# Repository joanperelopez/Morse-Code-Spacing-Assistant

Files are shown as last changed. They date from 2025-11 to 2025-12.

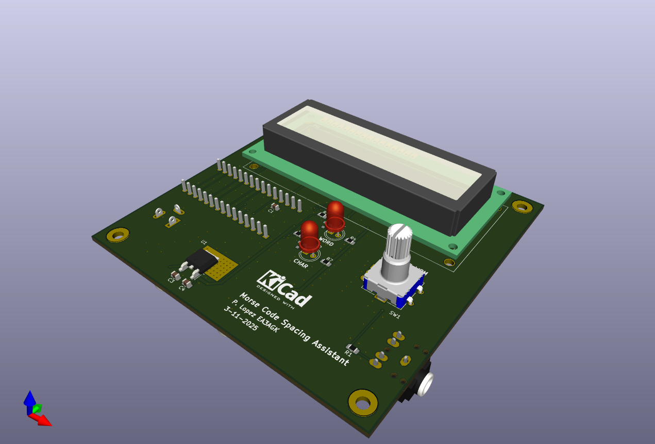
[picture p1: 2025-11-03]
IMAGES/Metronomo_TOP.png

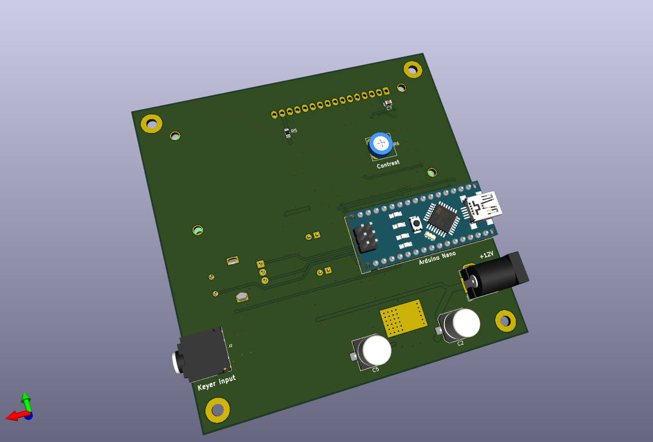
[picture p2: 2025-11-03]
IMAGES/Metronomo_BOT.png

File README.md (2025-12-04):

# Morse-Code-Spacing-Assistant

## 1. Overview
The **CW Visual Metronome** is a training device designed for radio amateurs practicing Morse code (CW).  
It helps the operator maintain correct **Farnsworth timing** between characters and words by providing **visual cues** through two LEDs.

The device monitors the keyer signal, detects symbol endings, and activates visual indicators at precise intervals derived from the selected **effective WPM** (Words Per Minute).

The system is based on an **Arduino Nano**, with a **1602 LCD display** showing the current speed, a **rotary encoder** for adjustment, and a **memory pushbutton** that stores the selected speed in non-volatile EEPROM memory. 

---

## 2. Functional Description

| Function | Description |
|---|---|
| **Keyer input** | Detects the Morse key line. When released, timing intervals begin. |
| **Character LED** | Lights up when the inter-character interval (3 dot units) has elapsed since the last key release. |
| **Word LED** | Lights up when the inter-word interval (7 dot units) has elapsed since the last key release. |
| **Rotary encoder** | Adjusts the effective Farnsworth speed (WPM). |
| **LCD display** | Shows the current Farnsworth speed in WPM. |
| **Memory button** | When pressed (active LOW), stores the current speed in EEPROM. |
| **EEPROM memory** | Retains the last stored speed; restored automatically at startup. |

---

## 3. Timing Definition (Farnsworth Method)

The Farnsworth method keeps the character speed constant but lengthens the spacing between characters and words to achieve a slower **effective WPM** for training.

The base time unit (*dot duration*) is calculated as:

Tdot = 1200 / WPM

| Interval | Duration (dot units) | Description |
|---|---|---|
| Dot (·) | 1 × Tdot | Base unit |
| Dash (–) | 3 × Tdot | Morse standard |
| Intra-character gap | 1 × Tdot | Between elements of a character |
| Inter-character gap | 3 × Tdot | Between two characters |
| Inter-word gap | 7 × Tdot | Between words |

LED indicators:
- **Character LED:** lights after *3 × Tdot* (character spacing).  
- **Word LED:** lights after *7 × Tdot* (word spacing).

---

## 4. User Interface and Operation

1. **Startup**
   - Reads stored speed from EEPROM.
   - Defaults to **15 WPM** if no valid data found.
   - Displays current speed on the LCD.

2. **Adjusting the Speed**
   - Turn the rotary encoder to change the Farnsworth speed.
   - Display updates in real time.

3. **Saving the Speed**
   - Press the *Memory Button* (active LOW) to save current WPM to EEPROM.
   - “Saved in EEPROM” appears briefly on the LCD.

4. **Operating Mode**
   - When the Morse key (active LOW) is pressed, both LEDs turn OFF.
   - After key release:
     - The **Character LED** turns ON after 3 dot units.
     - The **Word LED** turns ON after 7 dot units.
   - When the key is pressed again, both LEDs turn OFF immediately.

---

## 5. Hardware Specifications

| Component | Description |
|---|---|
| **Microcontroller** | Arduino Nano (ATmega328P) |
| **Display** | 1602 alphanumeric LCD |
| **Rotary Encoder** | Incremental (2-channel, mechanical) |
| **EEPROM** | Internal, used for WPM storage |
| **Indicators** | 2 LEDs (character and word) |
| **Memory Button** | Momentary pushbutton, active LOW |
| **Keyer Input** | From key or transceiver, active LOW |
| **Power Supply** | 5 V DC (USB or external) |

---

## 6. Pin Assignments

| Signal | Arduino Pin | Description |
|---|---|---|
| **Keyer input** | D2 | Active LOW, internal pull-up |
| **Encoder A** | D3 | Rotary encoder channel A |
| **Encoder B** | D4 | Rotary encoder channel B |
| **LCD D4** | D5 | Data line 4 |
| **LCD D5** | D6 | Data line 5 |
| **LCD RS** | D7 | Register Select |
| **LCD E** | D8 | Enable |
| **LED (character)** | D9 | Character spacing indicator |
| **LED (word)** | D10 | Word spacing indicator |
| **LCD D6** | D11 | Data line 6 |
| **LCD D7** | D12 | Data line 7 |
| **Memory button** | D21 | Active LOW, internal pull-up |

---

## 7. Electrical Characteristics

| Parameter | Typical Value | Notes |
|---|---|---|
| Supply Voltage | 5 V DC | Standard Arduino Nano |
| Logic HIGH | ≥ 3.0 V | TTL compatible |
| Logic LOW | ≤ 1.0 V | TTL compatible |
| LED Current | 10–15 mA | With 330 Ω series resistors |
| EEPROM Endurance | 100,000 write cycles | Managed via `EEPROM.update()` |

---

## 8. Software Summary

- Language: **C++ (Arduino IDE)**
- Main libraries used:
  - `LiquidCrystal.h` – LCD display control  
  - `RotaryEncoder.h` – rotary encoder handling  
  - `EEPROM.h` – non-volatile memory management
- Main functions:
  - Real-time LED timing based on keyer signal
  - Adjustable Farnsworth WPM
  - EEPROM storage of configuration
  - LCD visual feedback

---

## 9. Default Parameters

| Parameter | Default Value | Range |
|---|---|---|
| **Farnsworth speed** | 15 WPM | 5–40 WPM |
| **Character spacing** | 3 × Tdot | — |
| **Word spacing** | 7 × Tdot | — |

---

Metronomo_TOP
TOP view of the circuit

Metronomo_BOT
BOTTOM view of the circuit

Captura de pantalla 2025-11-12 a las 15 01 24
3D Model of the plastic cover

WhatsApp Image 2025-11-18 at 19 28 20 (1)

WhatsApp Image 2025-11-18 at 19 28 19 (1)

WhatsApp Image 2025-11-18 at 19 28 19

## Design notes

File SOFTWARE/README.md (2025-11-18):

## Last software modifications

### Version V2.2

Aplied an small speaker in pin 13 throug a 4,7 uF capacitor that sound in character and word timeout.

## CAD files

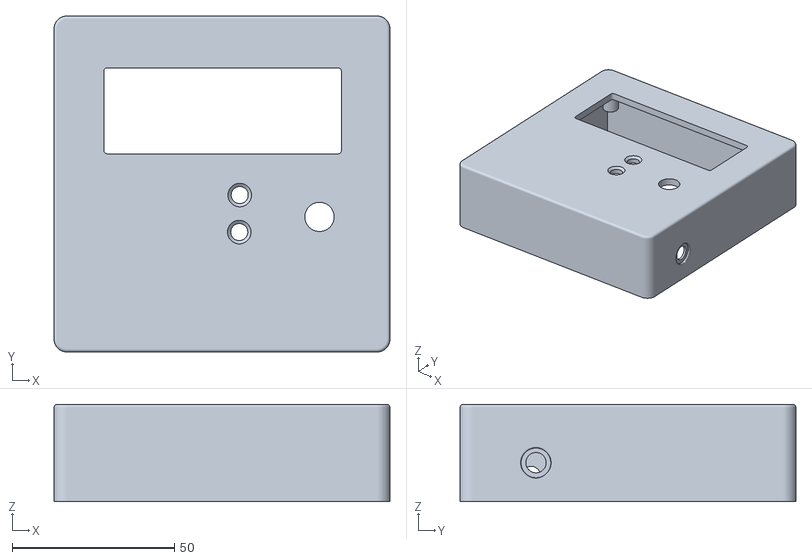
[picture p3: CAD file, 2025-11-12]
STL/caja_superior.stl
103.5 x 103.5 x 30.0

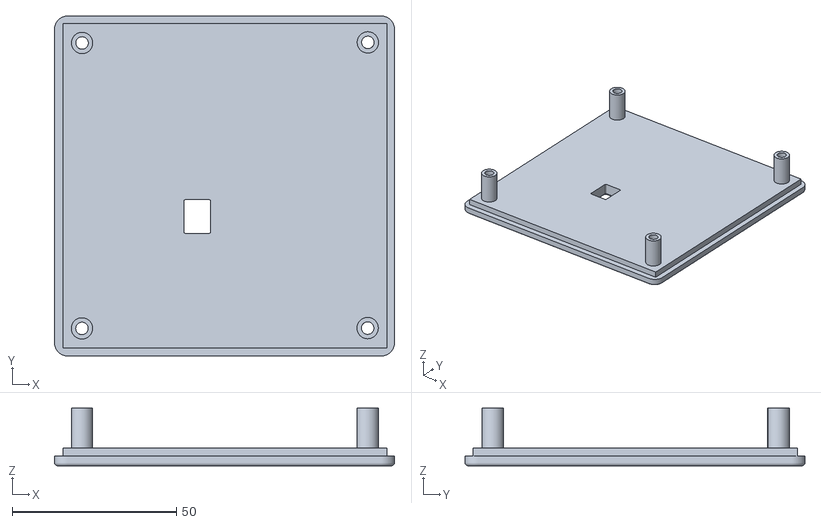
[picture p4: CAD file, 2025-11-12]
STL/Tapa.stl
103.5 x 103.5 x 17.6

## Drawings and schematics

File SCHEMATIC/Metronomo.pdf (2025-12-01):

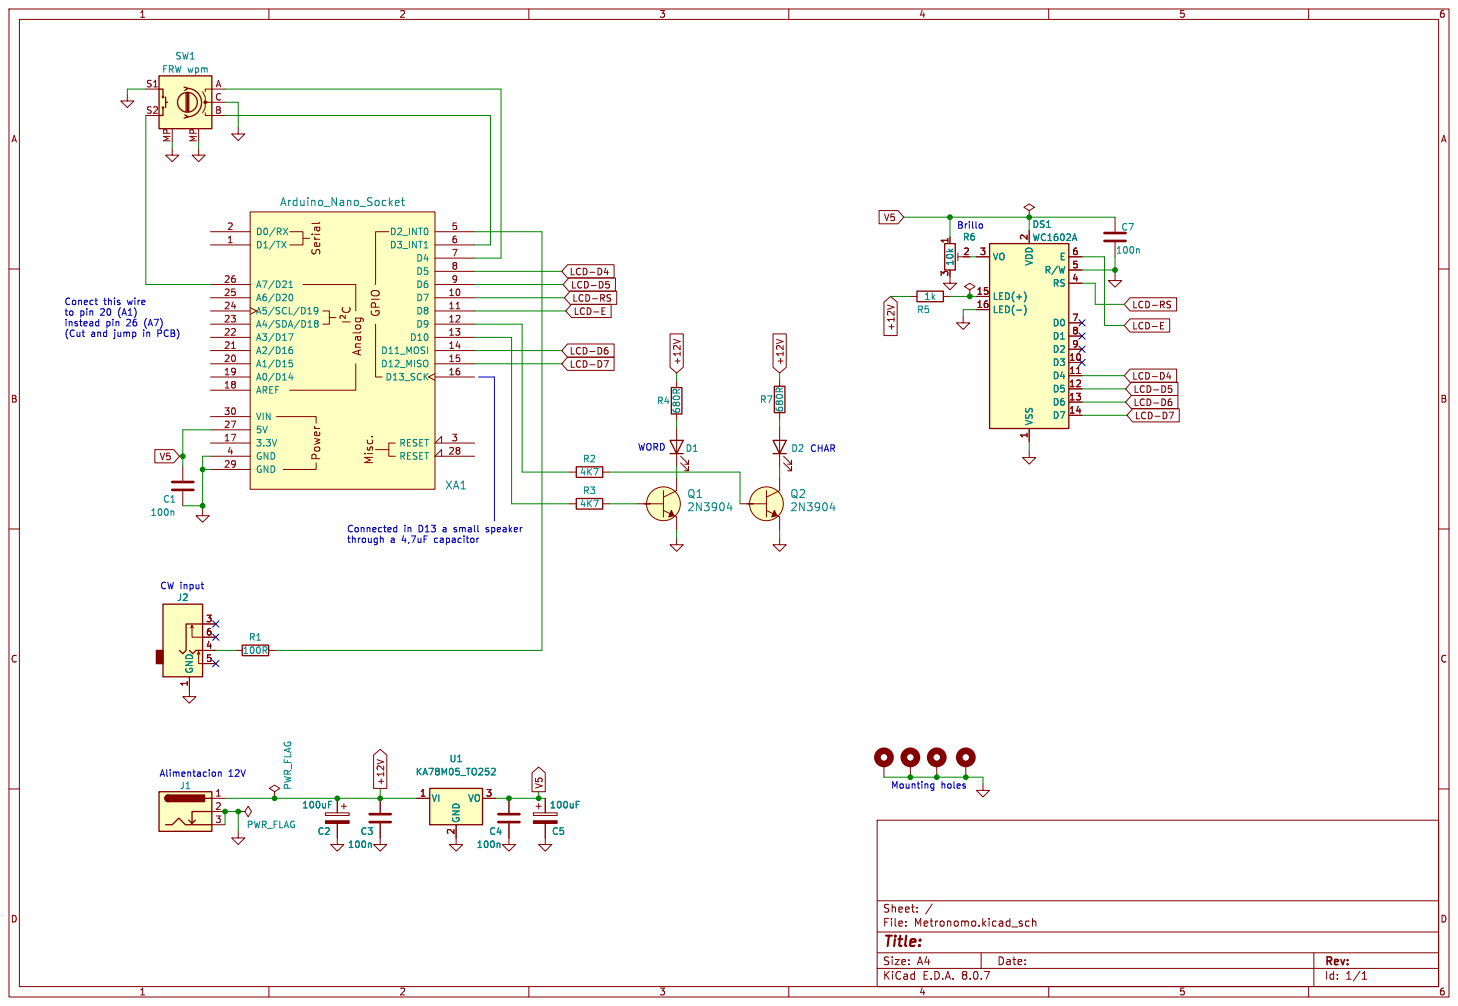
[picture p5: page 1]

LCD-D4 Connected in D13 a small speaker

to pin 20 (A1)
instead pin 26 (A7)
(Cut and jump in PCB)

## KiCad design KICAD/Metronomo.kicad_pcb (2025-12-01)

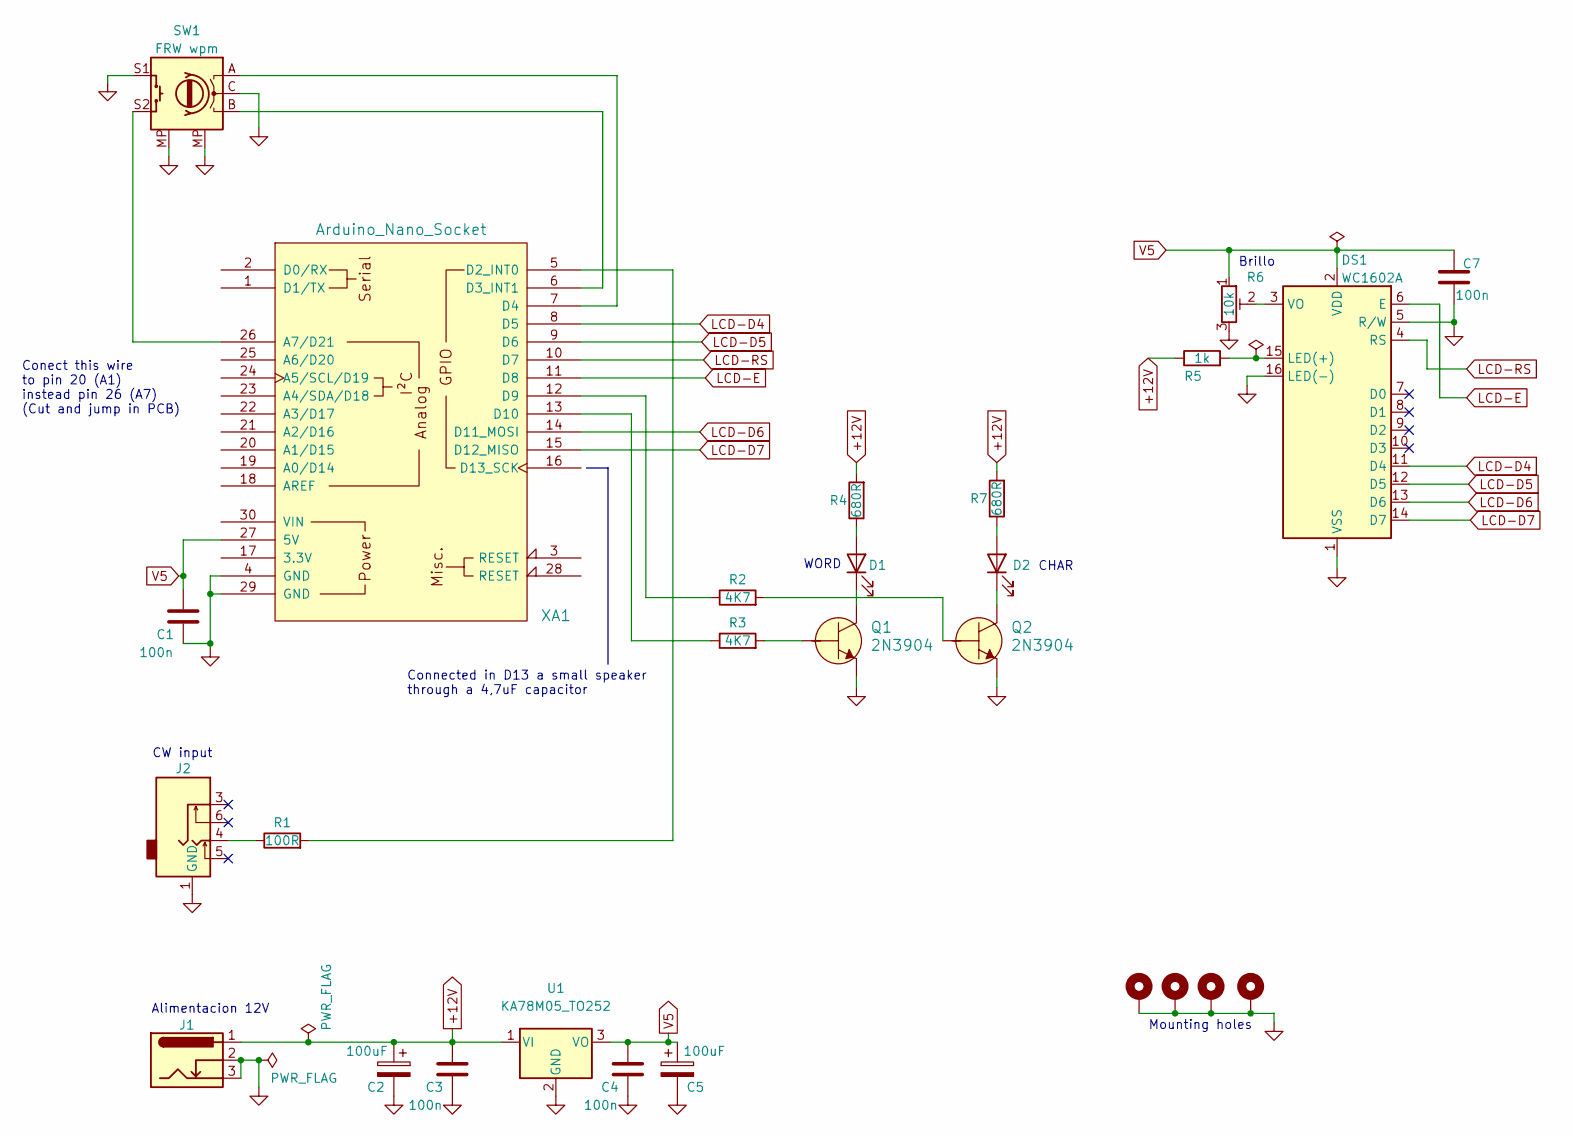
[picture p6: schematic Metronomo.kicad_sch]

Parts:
C1, C3, C4, C7: 100n; C_0805_2012Metric
C2, C5: 100uF; C_Elec_8x10.2
D1, D2: LED; LED_D5.0mm
DS1: WC1602A
H1, H2, H3, H4: MountingHole_Pad; MountingHole_3.2mm_M3_Pad_TopBottom
J1: Barrel_Jack_Switch_Pin3Ring; BarrelJack_GCT_DCJ200-10-A_Horizontal
J2: AudioJack4_PERE; AUDIO-JACK4
Q1, Q2: 2N3904; SOT23-3; MPN 2N3904; Digi-Key_PN 2N3904CS-ND
R1: 100R; R_0805_2012Metric_Pad1.20x1.40mm_HandSolder
R2, R3: 4K7; R_0805_2012Metric_Pad1.20x1.40mm_HandSolder
R4, R7: 680R; R_0805_2012Metric_Pad1.20x1.40mm_HandSolder
R5: 1k; R_0805_2012Metric_Pad1.20x1.40mm_HandSolder
R6: 10k; Potentiometer_Piher_PT-10-V10_Vertical
SW1: FRW wpm; RotaryEncoder_Alps_EC11E_Vertical_H20mm
U1: KA78M05_TO252; TO-252
XA1: Arduino_Nano_Socket; Arduino_Nano

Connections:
+12V: C2.1, C3.2, J1.1, R4.2, R5.1, R7.2, U1.1 (VI)
GND: C1.1, C2.2, C3.1, C4.1, C5.2, C7.1, DS1.1 (VSS), DS1.5 (R/W), DS1.16 (LED(-)), H1.1, H2.1, H3.1, H4.1, J1.2, J1.3, J2.1 (GND), Q1.2 (E), Q2.2 (E), R6.3, SW1.C, SW1.MP, SW1.S1, U1.2 (GND), XA1.4 (GND), XA1.29 (GND)
LCD-D4: DS1.11 (D4), XA1.8 (D5)
LCD-D5: DS1.12 (D5), XA1.9 (D6)
LCD-D6: DS1.13 (D6), XA1.14 (D11_MOSI)
LCD-D7: DS1.14 (D7), XA1.15 (D12_MISO)
LCD-E: DS1.6 (E), XA1.11 (D8)
LCD-RS: DS1.4 (RS), XA1.10 (D7)
unnamed: D1.2 (A), R4.1
unnamed: D1.1 (K), Q1.3 (C)
unnamed: D2.2 (A), R7.1
unnamed: D2.1 (K), Q2.3 (C)
unnamed: DS1.15 (LED(+)), R5.2
unnamed: DS1.3 (VO), R6.2
unnamed: J2.4, R1.1
unnamed: Q1.1 (B), R3.2
unnamed: Q2.1 (B), R2.2
unnamed: SW1.S2, XA1.26 (A7/D21)
unnamed: R1.2, XA1.5 (D2_INT0)
unnamed: SW1.B, XA1.6 (D3_INT1)
unnamed: SW1.A, XA1.7 (D4)
unnamed: R2.1, XA1.12 (D9)
unnamed: R3.1, XA1.13 (D10)
V5: C1.2, C4.2, C5.1, C7.2, DS1.2 (VDD), R6.1, U1.3 (VO), XA1.27 (5V)

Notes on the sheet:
Mounting holes
Connected in D13 a small speaker through a 4,7uF capacitor
Alimentacion 12V
CW input
CHAR
WORD
Conect this wire to pin 20 (A1) instead pin 26 (A7) (Cut and jump in PCB)
Brillo

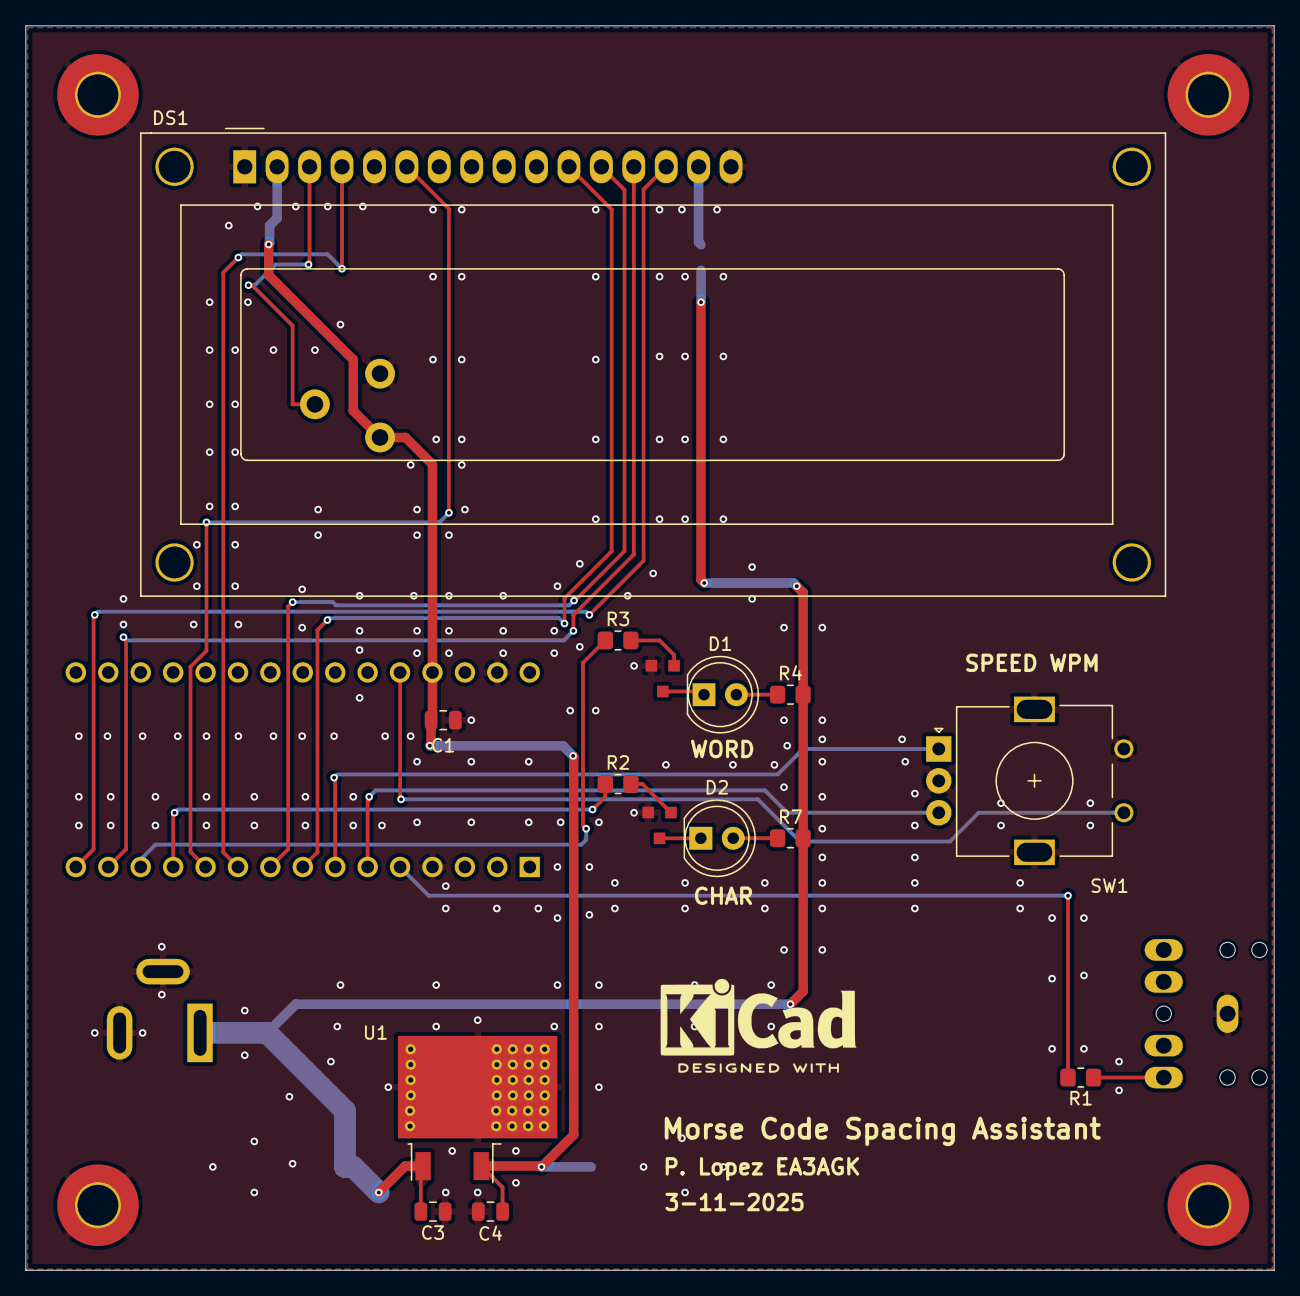
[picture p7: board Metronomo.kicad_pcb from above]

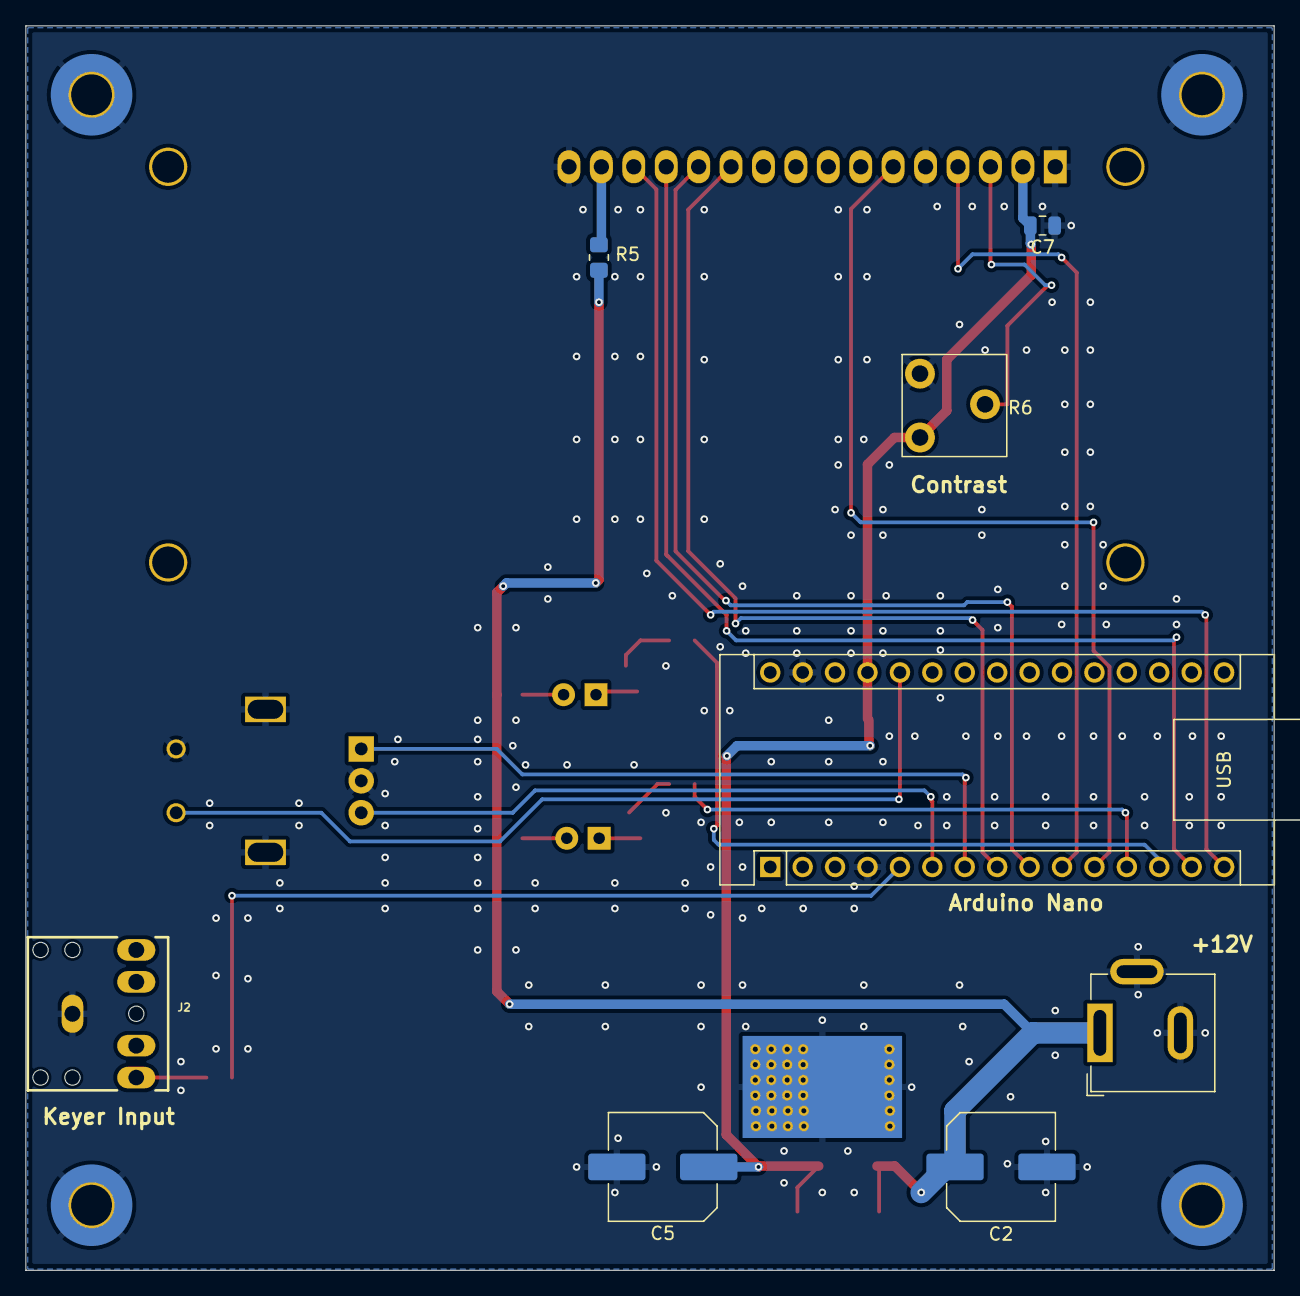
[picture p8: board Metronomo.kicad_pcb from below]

Board: 2 copper layers, 97.8 x 97.5 mm, 27 parts (8 on the bottom side), 24 nets.

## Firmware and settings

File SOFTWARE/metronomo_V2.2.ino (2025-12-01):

/*
  Version 2.2
  CW Visual and audio Metronome - Edit CHAR and FARM speeds
  Arduino Nano, PCB pinout as specified by Pere (EA3AGK)

  - Keyer input (active LOW)         : D2
  - Rotary encoder A/B               : D3, D4
  - LCD 1602 (4-bit)                 : D5 (D4), D6 (D5), D7 (RS), D8 (E), D11 (D6), D12 (D7)
  - LED character (char gap)         : D10
  - LED word (word gap)              : D9
  - Option button (active LOW)       : A2  (used with internal pull-up)
  - EEPROM:
      addr 0 -> wpm_char (5..35) default 25
      addr 1 -> wpm_eff  (5..35) default 6

  Behaviour implemented:
  - Normal operation as before (keyer -> LEDs based on Farnsworth spacing)
  - Press Option to enter edit CHAR mode (numeric blinks). Change with encoder (5..35).
    Timeout: 3 s of encoder inactivity -> save to EEPROM and exit edit.
    While moving the encoder the timeout is suspended (i.e. reset).
  - Press Option again while in CHAR edit -> switch to FARM edit (same behaviour).
  - If editing CHAR and new CHAR < current FARM, FARM is capped to CHAR when saving.
  - At startup read EEPROM values; if invalid use defaults (25, 6).
  - dot timing computed from wpm_char; spacing scaled so that effective spacing obeys wpm_eff:
      dot_ms = 1200 / wpm_char
      scale = wpm_char / wpm_eff  (>= 1)
      charGap = 3 * dot_ms * scale
      wordGap = 7 * dot_ms * scale

  Requires libraries: LiquidCrystal, RotaryEncoder, EEPROM
*/



#include <LiquidCrystal.h>
#include <RotaryEncoder.h>
#include <EEPROM.h>

// ---------------- PINES
const uint8_t PIN_KEYER    = 2;   // active LOW
const uint8_t PIN_ROT_A    = 3;
const uint8_t PIN_ROT_B    = 4;
const uint8_t PIN_LCD_D4   = 5;
const uint8_t PIN_LCD_D5   = 6;
const uint8_t PIN_LCD_RS   = 7;
const uint8_t PIN_LCD_E    = 8;
const uint8_t PIN_LED_CHAR = 10;
const uint8_t PIN_LED_WORD = 9;
const uint8_t PIN_LCD_D6   = 11;
const uint8_t PIN_LCD_D7   = 12;
const uint8_t PIN_OPTION   = A1;  // active LOW, internal pull-up
const uint8_t pinBuzzer    = 13;   

// ---------------- HARDWARE OBJECTS
LiquidCrystal lcd(PIN_LCD_RS, PIN_LCD_E,
                  PIN_LCD_D4, PIN_LCD_D5,
                  PIN_LCD_D6, PIN_LCD_D7);

RotaryEncoder encoder(PIN_ROT_A, PIN_ROT_B);

// Nuevas variables para el calculo del Farnsworth
float t_dot;       // duración de un dit según wpm_char
float t_dot_eff;   // duración de un dit según wpm_eff
float t_info;      // tiempo total del mensaje Morse, sin Farnsworth
float t_totalSlots; 
float t_slot;      
float n_slots;     

float t_char_sec;  // segundos entre caracteres
float t_word_sec;  // segundos entre palabras

// ---------------- EEPROM & defaults
const uint8_t ADDR_CHAR = 0;
const uint8_t ADDR_EFF  = 1;

const int DEF_CHAR = 25;
const int DEF_EFF  = 6;
const int MIN_WPM = 3;
const int MAX_WPM = 40;

// ---------------- ESTADO
int wpm_char = DEF_CHAR;
int wpm_eff  = DEF_EFF;

unsigned long charGap_ms = 0;
unsigned long wordGap_ms = 0;

unsigned long lastKeyRelease_ms = 0;
bool lastKeyState = HIGH;
bool keyState;


enum Mode { MODE_NORMAL, MODE_EDIT_CHAR, MODE_EDIT_FARM };
Mode modeNow = MODE_NORMAL;

int editValue = 0;

// encoder pos tracking
long encLastPos = 0;

// edit timing & blink
unsigned long lastEncoderActivity = 0;
const unsigned long EDIT_TIMEOUT = 3000UL; // 3 s
unsigned long lastBlink = 0;
const unsigned long BLINK_MS = 500UL;
bool blinkOn = true;
bool valueMoved = false;

// option button debounce
bool optLastRaw = HIGH;
unsigned long optDebounceTime = 0;
const unsigned long OPT_DEBOUNCE_MS = 40;
static bool optLastStable = HIGH;


// Timer LEDs

unsigned long startTime = 0;
bool waitingToTurnOn_C = false;
bool waitingToTurnOn_W = false;
bool buttonWasPressed = false;



// ---------------- FUNCIONES AUXILIARES

// Funcion de calculo del Farnsworth
void computeFarnsworthTiming(int wpm_char, int wpm_eff) {
  t_dot = 60.0 / (wpm_char * 50.0);
  t_dot_eff = 60.0 / (wpm_eff * 50.0);

  t_info = t_dot * (50 - 19) * wpm_eff;

  t_totalSlots = 60.0 - t_info;

  n_slots = 3.0 * ((wpm_eff * 5) - wpm_eff) + 7.0 * wpm_eff;

  t_slot = t_totalSlots / n_slots;

  t_char_sec = 3.0 * t_slot*1.1;          // Para cálculo de tiempo en segundos
  t_word_sec = 7.0 * t_slot*1.1;          // Para calculo de tiempo en segundos

  charGap_ms = (unsigned long)(t_char_sec * 1000.0 + 0.5);
  wordGap_ms = (unsigned long)(t_word_sec * 1000.0 + 0.5);
}

//*******************************************
// Mostrar los tiempos en el LCD
void showLEDTimes() {
  lcd.setCursor(13,0);
  lcd.print("    ");
  lcd.setCursor(13,0);
  lcd.print(t_char_sec,2);

  lcd.setCursor(13,1);
  lcd.print("    ");
  lcd.setCursor(13,1);
  lcd.print(t_word_sec,2);
}

//*******************************************
// Lectura NVM
int safeReadEEP(int addr, int defv) {
  int v = EEPROM.read(addr);
  if (v < MIN_WPM || v > MAX_WPM) return defv;
  return v;
}
// Lectura NVM
void loadEEP() {
  wpm_char = safeReadEEP(ADDR_CHAR, DEF_CHAR);
  wpm_eff  = safeReadEEP(ADDR_EFF, DEF_EFF);
  if (wpm_eff > wpm_char) wpm_eff = wpm_char;
  computeFarnsworthTiming(wpm_char, wpm_eff);
}
// Guardar en NVM velocidad de caracter
void saveCharEEP() {
  EEPROM.update(ADDR_CHAR, (uint8_t)wpm_char);
}
// Guardar en NVM velocidad Farnsworth
void saveEffEEP() {
  EEPROM.update(ADDR_EFF, (uint8_t)wpm_eff);
}

// pantallas
//Vista normal del display
void showNormal() {
  lcd.clear();
  lcd.setCursor(0,0);
  lcd.print("CHAR:");
  lcd.setCursor(6,0);
  if (wpm_char < 10) lcd.print('0');
  lcd.print(wpm_char);
  lcd.print(" wpm");

  lcd.setCursor(0,1);
  lcd.print("FARM:");
  lcd.setCursor(6,1);
  if (wpm_eff < 10) lcd.print('0');
  lcd.print(wpm_eff);
  lcd.print(" wpm");

  showLEDTimes();       // Se muestran los tiempos en segundos
}

// Pantalla de edición
// Display de edición
void showEditHeader(Mode m) {
  lcd.clear();
  if (m == MODE_EDIT_CHAR) {
    lcd.setCursor(0,0); lcd.print("CHAR:");
  } else {
    lcd.setCursor(0,0); lcd.print("FARM:");
  }
  lcd.setCursor(11,0); lcd.print(" wpm");
}

void updateEditNumber(Mode m, int value, bool showNumber) {
  lcd.setCursor(6,0);
  if (showNumber) {
    if (value < 10) lcd.print('0');
    lcd.print(value);
  } else {
    lcd.print("  ");
  }
}

// option button detection
bool optionPressed() {
  bool raw = digitalRead(PIN_OPTION);
  if (raw != optLastRaw) {
    optDebounceTime = millis();
    optLastRaw = raw;
  }
  if ((millis() - optDebounceTime) > OPT_DEBOUNCE_MS) {
    if (optLastStable == HIGH && raw == LOW) {
      optLastStable = raw;
      return true;
    }
    optLastStable = raw;
  }
  return false;
}

//****************************************
// ---------------- SETUP
void setup() {
  pinMode(PIN_KEYER, INPUT_PULLUP);
  pinMode(PIN_OPTION, INPUT_PULLUP);
  pinMode(PIN_LED_CHAR, OUTPUT);
  pinMode(PIN_LED_WORD, OUTPUT);

  digitalWrite(PIN_LED_CHAR, LOW);
  digitalWrite(PIN_LED_WORD, LOW);

  waitingToTurnOn_C = true;     // Temporizador
  waitingToTurnOn_W = true;

  Serial.begin(115200);   
  lcd.begin(16,2);

  loadEEP();
  showNormal();

  encoder.setPosition(0);
  encLastPos = encoder.getPosition();
  lastEncoderActivity = millis();
  lastBlink = millis();

  lastKeyState = digitalRead(PIN_KEYER);
  lastKeyRelease_ms = millis();
  lastKeyRelease_ms = 0;
}

//****************************************
// ---------------- LOOP
void loop() {
  encoder.tick();
  long encPos = encoder.getPosition();
  long delta = encPos - encLastPos;


  // OPTION button
  if (optionPressed()) {
    if (modeNow == MODE_NORMAL) {
      modeNow = MODE_EDIT_CHAR;
      editValue = wpm_char;
      encoder.setPosition(0); encLastPos = 0;
      lastEncoderActivity = millis();
      blinkOn = true; lastBlink = millis();
      showEditHeader(MODE_EDIT_CHAR);
      updateEditNumber(MODE_EDIT_CHAR, editValue, blinkOn);
      valueMoved = false;
    } else if (modeNow == MODE_EDIT_CHAR) {
      modeNow = MODE_EDIT_FARM;
      editValue = wpm_eff;
      encoder.setPosition(0); encLastPos = 0;
      lastEncoderActivity = millis();
      blinkOn = true; lastBlink = millis();
      showEditHeader(MODE_EDIT_FARM);
      updateEditNumber(MODE_EDIT_FARM, editValue, blinkOn);
      valueMoved = false;
    } else if (modeNow == MODE_EDIT_FARM) {
      modeNow = MODE_EDIT_CHAR;
      editValue = wpm_char;
      encoder.setPosition(0); encLastPos = 0;
      lastEncoderActivity = millis();
      blinkOn = true; lastBlink = millis();
      showEditHeader(MODE_EDIT_CHAR);
      updateEditNumber(MODE_EDIT_CHAR, editValue, blinkOn);
      valueMoved = false;
    }
  }

  // --- Edición
  if (modeNow == MODE_EDIT_CHAR || modeNow == MODE_EDIT_FARM) {
    if (delta != 0) {
      if (delta > 0) {
        for (long i=0;i<delta;i++) { editValue++; if (editValue>MAX_WPM){editValue=MAX_WPM; break;} }
      } else {
        for (long i=0;i<-delta;i++) { editValue--; if (editValue<MIN_WPM){editValue=MIN_WPM; break;} }
      }
      lastEncoderActivity = millis();
      valueMoved = true;
      blinkOn = true; lastBlink = millis();
      updateEditNumber(modeNow, editValue, blinkOn);
      encLastPos = encPos;
    }

    if (millis() - lastBlink >= BLINK_MS) {
      lastBlink = millis();
      blinkOn = !blinkOn;
      updateEditNumber(modeNow, editValue, blinkOn);
    }

    if (millis() - lastEncoderActivity >= EDIT_TIMEOUT) {
      if (modeNow == MODE_EDIT_CHAR) {
        wpm_char = editValue;
        if (wpm_eff > wpm_char) { wpm_eff = wpm_char; saveEffEEP(); }
        saveCharEEP();
        computeFarnsworthTiming(wpm_char, wpm_eff); // sólo aquí
        showLEDTimes();

        modeNow = MODE_EDIT_FARM;
        editValue = wpm_eff;
        encoder.setPosition(0); encLastPos = 0;
        lastEncoderActivity = millis();
        blinkOn = true; lastBlink = millis();
        showEditHeader(MODE_EDIT_FARM);
        updateEditNumber(MODE_EDIT_FARM, editValue, blinkOn);
        valueMoved = false;
      } else {
        if (editValue > wpm_char) editValue = wpm_char;
        wpm_eff = editValue;
        saveEffEEP();
        computeFarnsworthTiming(wpm_char, wpm_eff); // sólo aquí
        showLEDTimes();

        modeNow = MODE_NORMAL;
        showNormal();
      }
    }

  } else {
    encLastPos = encPos;
  }






  // --- KEYER & LEDs
  unsigned long now = millis();
  bool buttonPressed = (digitalRead(PIN_KEYER) == LOW);

 // Detectar flanco de bajada (cuando se pulsa por primera vez)
  if (buttonPressed && !buttonWasPressed) {
    digitalWrite(PIN_LED_CHAR, LOW);
    digitalWrite(PIN_LED_WORD, LOW);
//    Serial.println("Pasa por aquí");
    startTime = millis();
    waitingToTurnOn_C = true;
    waitingToTurnOn_W = true;
    buttonWasPressed = buttonPressed;
  }


// Si estamos esperando y ya pasó el tiempo, enciende el LED
  if ((waitingToTurnOn_C||waitingToTurnOn_W)&& !buttonPressed) {
// Aquí se miran que led hay que encender  
      if (waitingToTurnOn_C && (millis() - startTime >= charGap_ms)) {
          digitalWrite(PIN_LED_CHAR, HIGH);
          waitingToTurnOn_C = false;
          tone(pinBuzzer, 2500, 100);   // 2500 Hz durante 100 ms
          } 
    if (waitingToTurnOn_W && (millis() - startTime >= wordGap_ms)) {
          digitalWrite(PIN_LED_WORD, HIGH);
          waitingToTurnOn_W = false;
          tone(pinBuzzer, 300, 200);   // 300 Hz durante 200 ms
          }
  }
  

  buttonWasPressed = buttonPressed;

// Depuracion solo
/*
Serial.print("startTime: ");
Serial.print(startTime);

Serial.print(".   buttonPressed: ");
Serial.println(buttonPressed);

*/





}

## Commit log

2025-11-03 Enhance README with comprehensive device details
    Expanded the README with detailed sections on user interface, hardware specifications, electrical characteristics, software summary, default parameters, and author information.
2025-11-03 Update README to remove author and add circuit images
    Removed author section and added images of the circuit.
